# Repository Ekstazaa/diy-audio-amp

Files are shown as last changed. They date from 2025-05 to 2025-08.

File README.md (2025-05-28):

# diy-audio-amp
This is a modular analog audio amplifier project designed for educational and hobby use. It is composed of clearly separated functional blocks such as input stage, voltage amplification, output stage, and power supply – making it easy to understand, modify, or reuse in other designs.

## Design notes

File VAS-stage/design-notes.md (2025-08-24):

# VAS - Voltage Amplifier Stage

The Voltage Amplification Stage (VAS) is a crucial part of any audio power amplifier. Its main role is to amplify the small signal coming from the input stage to a level close to the full supply voltage swing, preparing it to drive the output stage. In other words, the VAS is responsible for faithfully reproducing the input waveform but with a much larger amplitude.

Because of its key role, the operating point of the VAS transistor is extremely important. Poor biasing or incorrect design can lead to severe non-linearity, distortion, and reduced bandwidth.

For beginners, the most common and practical implementation of the VAS is the common-emitter amplifier. This topology provides high voltage gain, good linearity (when properly biased), and simplicity, making it the standard starting point for amplifier design.

## Common Emitter configuration



The circuit shown above is the most classic and academic transistor configuration, making it a great starting point.

Its operation is simple to understand: when the input voltage rises, the NPN transistor begins to conduct heavily, effectively pulling the collector toward ground — the output drops.
When the input voltage decreases, the transistor enters cutoff, and the output approaches the supply voltage.
If we interpret the signals as logic states, this stage acts as an inverter, introducing a 180° phase shift between input and output.

Because of the transistor’s current amplification, a relatively small change in input voltage can produce a large change at the output. This is the foundation of its high voltage gain, making the common-emitter stage a key building block in amplifiers.

### Operating point

### Gain

### Input Impednace

### Output Impedance

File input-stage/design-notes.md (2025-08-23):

## Input stage configurations

For the input stage, the most common solution is a differential pair. The main advantage of this configuration is the ability to apply negative feedback, which can be used to compensate for various non-idealities. For this chapter I will explain basic work of differential pair, parameters and some improvements.

## JFET vs BJT

In audio design books, the best choice for input stages for power amplifiers are.. BJT. The main reasons are their higher linearity, greater gain, and better temperature stability compared to FETs. The only real drawback of BJTs is the presence of base current, which reduces input impedance. However, in most cases, this trade-off is worth it due to the other significant advantages.

# Differential pair



A differential pair is a circuit built from two **identical** transistors with same load supplied by a constant current source. The core idea is that the current through each transistor depends on the voltage difference between the two inputs. If both inputs are equal, the current splits evenly — each side conducts I/2. When vin1 is higher than vin2, more current flows through the transistor on the right side what causes higher voltage on vout2 and vice versa. 



At start let's look at the chart above. It shows how the current through resistors R1 and R2 changes depending on the voltage difference between the inputs (note: negative values indicate that vin1 < vin2).
This graph has few conclusions:

1. The characteristic curve assumes perfectly matched transistors, which means the current splits evenly (I/2) when the voltage difference is exactly 0 V. In reality, transistors can have slight mismatches due to manufacturing tolerances, leading to input offset current or voltage, even when vin1 = vin2.
2. The linear operating region of the differential pair is quite narrow (it is assumed that narrow has 4<sub>*</sub>V<sub>T</sub> = 100 mV for normal configuration). This means the input stage is very sensitive, and even a small voltage difference between the inputs can lead to a significant imbalance in output current - in other words differencial pair has huge gain.
3. As we move further outside the linear range, one of the transistors starts to dominate entirely, conducting nearly the full bias current, while the other one effectively shuts off. At this point, the circuit loses its linear behavior and enters a region where the output no longer changes proportionally to the input difference. In practical terms, this limits show how large the differential input voltage can be **before distortion appears**.

In audio designs the input signal is kept within the linear region otherwise we can introduce distortions to our circuit.

## Gains of differental pair

Just like the differential pair has two inputs, it also has two outputs. Because of that, we can define three different types of voltage gain, depending on how we observe the outputs:
1. Gain measured at `vout1`:

**A<sub>v1</sub> = -R<sub>C</sub> / (2 · r<sub>eb'</sub>) = -1/2 · g<sub>m</sub> · R<sub>C</sub>**

2. Gain measured at `vout2`:

**A<sub>v2</sub> = R<sub>C</sub> / (2 · r<sub>eb'</sub>) = 1/2 · g<sub>m</sub> · R<sub>C</sub>**

3. Differential gain:

**A<sub>v_diff</sub> = R<sub>C</sub> / r<sub>eb'</sub> = g<sub>m</sub> · R<sub>C</sub>**

Where:
- `RC` is the collector resistance,
- `reb' = VT / IC` is the internal emitter resistance,
- `VT` is the thermal voltage (≈ 25 mV at room temperature).

## Input Resistance

As I mentioned earlier when discussing BJTs, one of the key issues is the input impedance, since a continuous base current flows into the transistor.

From the perspective of the PNP transistor currnet is going from emitter to input, so we consider r<sub>b'e</sub> for both transistors in the differential pair:

**R<sub>in</sub> = 2 · r<sub>b'e</sub> = 2 · β · r<sub>eb'</sub>**

## CMRR 

CMRR (Common-Mode Rejection Ratio) is the ability of an amplifier to reject noise that appears equally on both inputs. Formally, it is defined as the ratio between the differential gain (A<sub>diff</sub>) and the common-mode gain(A<sub>cm</sub>) and that mean we would like to have it as huge as it's posible and the best solution is to provide large differential gain.

**CMRR = 20 · log(A<sub>diff</sub>/A<sub>cm</sub>)**

## Load of differential pair

For a differential pair, even with a simple implementation, you can identify three main variants of loading:
a) Unbalanced resistive load
b) Balanced load using resistors
c) Balanced load with a current mirror

In our case, the pair will eventually be loaded by the next stage (VAS), which introduces imbalance between the branches. This makes solution (a), using equal resistors in both collectors, a less attractive choice.

Circuit (b) improves the situation by using a single resistor to balance the load, but this is still only a passive compensation method.
The best solution is (c) — the current mirror load — because the transistor in the unloaded branch biases the other transistor, forcing an identical current in the loaded branch. This ensures excellent balance and better performance. Moreover, method (c) offers the best linearity among the three.



## Slew rate

Slew rate is a parameter that defines how quickly an amplifier can change its output voltage, effectively determining how fast it can turn the next stage on or off.

**Slew rate = dVout/dt = Iss/CL

For a differential pair with a current mirror load, the concept is easier to explain:

- When discharging the load, we assume that transistor M2 is fully on and M1 is off. In that case, the entire tail current from the pair’s current source flows through M2 to ground.

- Conversely, when charging the load, the process also happens with a current equal to the current source value.

Differential pairs with resistive loads typically have an asymmetrical slew rate, because the load resistor diverts part of the current, reducing the effective charging or discharging capability.



# Summary

For final design i used combination below:



If you are using a common differential pair with a current mirror load, there is not much you can adjust beyond selecting the transistors and setting the operating point via the current source. I chose the transistors based on their maximum V<sub>CE</sub> (50 V) for safety, and then balanced cost against noise performance. If you are more precise, you can look at β parameter which is mainly relevant for the input pair, since a higher value ensures greater input impedance.

As the current source, I used a configuration with a transistor biased by diodes and a resistor. I also added a potentiometer to allow fine-tuning if needed, and a capacitor Cf1 for filtering, because some AC signal was leaking into the bias voltage.

Initially, I started with 2.5 mA from the source, but after building the whole configuration I decided to reduce it to 1.88 mA.
Keep in mind that this current not only sets the operating point but also affects your gain — and, more importantly, your slew rate.

As mentioned earlier, slew rate defines how fast your circuit can respond. If it’s too slow, the amplifier can start cutting off higher audio frequencies. If it’s too fast, you risk turning your design into an oscillator due to the effects of negative feedback.

Bibliography:
1. Douglas Self, Audio Power Amplifier Design Handbook 4th edition, Elsevier, 2006
2. R. J. Baker, Circuit Design, Layout, and Simulation 3th Edition, Wiley, 2010

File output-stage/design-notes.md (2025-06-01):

## Output Stage Configurations

Before getting into the test results, I want to briefly go over the most common output stage configurations found in audio amplifiers. The two that come up the most are:

- **CFP – Complementary Feedback Pair (also known as the Sziklai pair)**  
- **EF – Emitter Follower (also known as the Darlington pair)**

Both of these topologies actually come from earlier **quasi-complementary designs**, which were developed when good PNP power transistors weren’t widely available. Nowadays, since complementary NPN/PNP devices are easy to get, using full complementary symmetry just makes more sense.



For this project, I decided to use the **CFP configuration**. After reading Rod Elliott’s article [2], I got the impression that it’s generally better suited for audio amplifiers. It tends to produce less distortion than other topologies. Of course, the actual difference between CFP and EF is often small and usually not audible unless you really know what to listen for — and even then, it can be purely subjective.

Still, from a design perspective, the CFP offers better linearity and thermal behavior, and that was enough for me to go with it.

To wrap up the topic of output stage topologies, I should also mention triple configurations, which basically just add more transistors to the chain. From what I’ve read, these are mostly used in commercial designs, where high current efficiency is a priority. As you can probably guess, that kind of complexity isn’t really necessary for this DIY project.

## Theory of shiklai

Let's look at this configuration:



The Shiklai pair is made of a power transistor (Q1) and control transistor (Q2). The main idea is to make the vout closely follow vin. When vin increases, Q2 starts to conduct more, which means that the base current of Q1 also increases. As a result, the output current delivered to the load goes up, causing vout to rise, so as to ensure a constant voltage drop across Q2's Vbe.

Sziklai pair behaves like a Darlington configuration, but with local negative feedback, which improves linearity and control.

In that configuration i used also ressistor R1. It helps to turn off/on Q1 by creating a voltage drop on Q1's Veb faster. In theory, the resistor should be as small as possible, but a balanced value is needed. If it's too small, it can lead to instability and reduced linearity due to excessive loop gain and insufficient damping.

## Simulations

In the testbench, I used the same current source that will be implemented in the final amplifier design to make the simulation results more realistic. The circuit was tested with a ±10 V, 1 kHz input signal, and the analysis covered 10 cycles. A 32 Ω resistor was used as the load:

Screenshot of testbench:



The two main things I can tweak are the transistors in the Sziklai pair and the resistors. For the control transistors, I chose BC556B and BC557B, mainly to keep the design coherent — differencial pair, current soures and VAS I used the same.

As for the power transistors, I went with 2SA1943 and 2SC5200. I picked these mostly based on cost and availability. Honestly, I don’t have much experience with selecting "ideal" transistors yet, so I just chose the most common and affordable ones I could find.

After analyzing the transistors, I tested the influence of resistors R1 and R2 by sweeping their values in LTspice.

| R [Ω] | THD [%] | AVG(i(vup)) [mA] | AVG(i(vdn)) [mA] |
|---|---|---|---|
| 100 | 0.0885  | 108.936 | -88.531 |
| 200 | 0.0689  | 109.449 | -89.033 |
| 300 | 0.0808  | 111.864 | -91.442 |
| 400 | 0.0808  | 113.779 | -93.353 |
| 500 | 0.0775  | 115.219 | -94.790 |
| 600 | 0.0753  | 116.255 | -95.824 |
| 700 | 0.0724  | 117.143 | -96.712 |
| 800 | 0.0704  | 117.841 | -97.408 |
| 900 | 0.0676  | 118.486 | -98.054 |
| 1000  | 0.0659  | 119.007 | -98.575 |
| 2000  | 0.0554  | 122.078 | -101.644 |
| 3000  | 0.0513  | 123.594 | -103.158 |
| 4000  | 0.0492  | 124.566 | -104.128 |
| 5000  | 0.0476  | 125.261 | -104.827 |
| 10000 | 0.0439  | 127.274 | -106.830 |

As a reminder, the resistor is used to accelerate the switching of the power transistors. The chart shows that when the resistance is high, the circuit struggles to turn off transistors Q1 and Q3. For values around 10 kΩ and higher, the transistors remain on throughout the entire cycle and operate in saturation. This indicates that the circuit behaves like a Class A amplifier.

Additionally, the average current through the branch increases with higher resistance values. To reduce power consumption, lower resistor values are needed. However, this comes with a trade-off: reducing the resistance increases THD and decreases linearity (you can see the breakdown in the characteristic). As always, it’s a matter of compromise.

I initially spent a lot of time analyzing that configuration for myself, but in practice, using 100Ω, 200Ω, or 300Ω doesn't really make much of a difference, since the resistance will drift with temperature regardless. The safest option is to choose a 330 Ω resistor from the E6 series.



Bibliography:
1. Douglas Self, Audio Power Amplifier Design Handbook 4th edition, Elsevier, 2006
2. Rod Elliott, Compound Pair Vs. Darlington Pairs, https://sound-au.com/articles/cmpd-vs-darl.htm, 2011

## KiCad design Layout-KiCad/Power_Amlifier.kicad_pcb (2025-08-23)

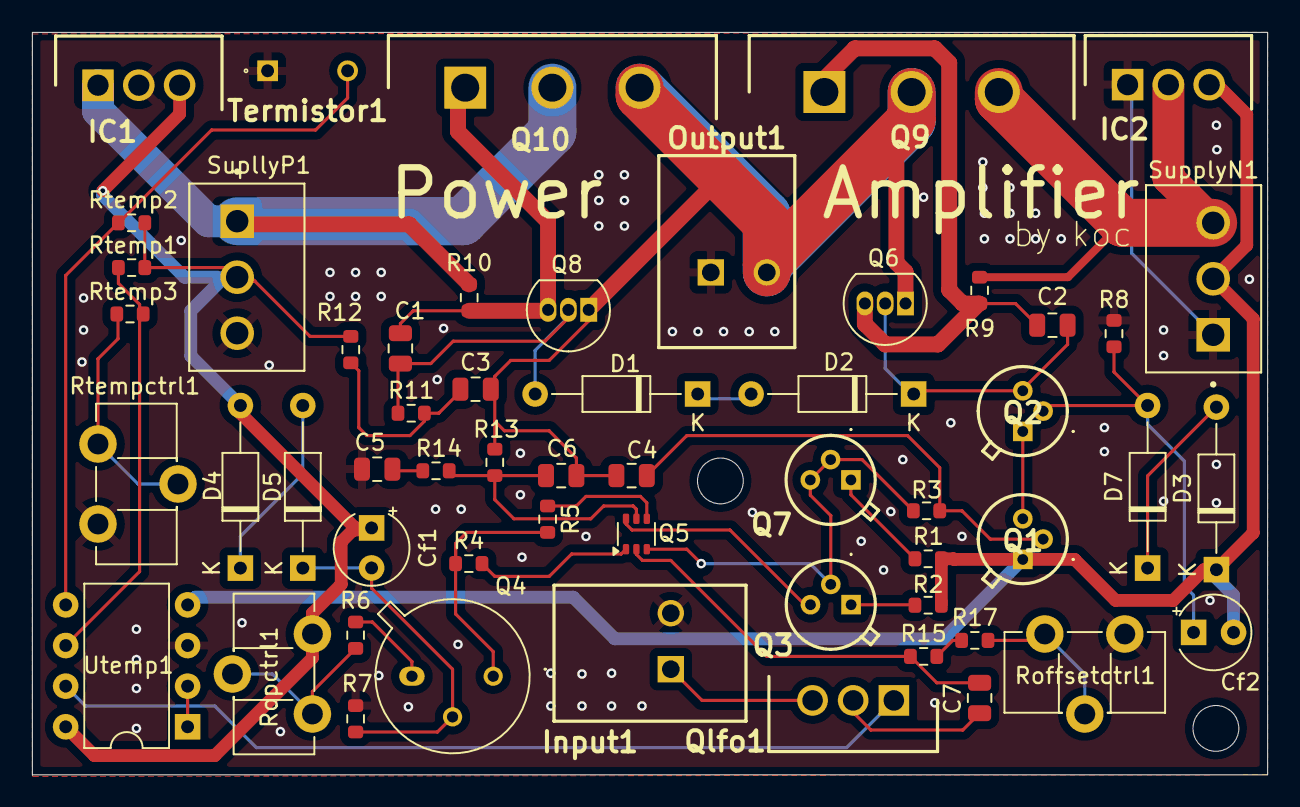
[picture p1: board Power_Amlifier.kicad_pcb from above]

Board: 2 copper layers, 77.2 x 46.4 mm, 56 parts (0 on the bottom side), 39 nets.

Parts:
C1, C2: 100p; C_0805_2012Metric
C3, C5: 10u; C_0805_2012Metric
C4: 470p; C_0805_2012Metric
C6: 2p2; C_0805_2012Metric
C7: 1.5n; C_0805_2012Metric
Cf1, Cf2: 100u; CP_Radial_Tantal_D4.5mm_P2.50mm
D1, D2, D3, D4, D5, D7: 1N914; D_DO-35_SOD27_P10.16mm_Horizontal
IC1, IC2: L7824CV; TO255P460X1020X2008-3P
Input1: 250-102; 250102
Output1: 250-102; 250102
Q1, Q2, Q3, Q7: 2N2484
Q4: BC303; TO-39-3
Q5: BC856BS; SOT-363_SC-70-6
Q6: Q_PNP_EBC; TO-92_Inline
Q8: Q_NPN_EBC; TO-92_Inline
Q9: 2SC5200-O_Q_; TO545P520X2000X2900-3P
Q10: 2SA1943-O_Q_; TO545P520X2050X2650-3P
Qlfo1: IRFZ34NPBF; TO254P469X1042X1967-3P
R1, R2: 220; R_0603_1608Metric
R3: 1; R_0603_1608Metric
R4, R5: 100; R_0603_1608Metric
R6, R9, R10: 330; R_0603_1608Metric
R7, R11, R12, R17: 10k; R_0603_1608Metric
R8: 470k; R_0603_1608Metric
R13: 220k; R_0603_1608Metric
R14: 11k; R_0603_1608Metric
R15: 200k; R_0603_1608Metric
Roffsetctrl1: R20k; Potentiometer_ACP_CA9-H5_Horizontal
Ropctrl1: R1k; Potentiometer_ACP_CA9-H5_Horizontal
Rtemp1, Rtemp2: 47k; R_0603_1608Metric
Rtemp3: 5k; R_0603_1608Metric
Rtempctrl1: R10k; Potentiometer_ACP_CA9-H5_Horizontal
SupllyP1: TBP03R2-350-03BE; CUI_TBP03R2-350-03BE
SupplyN1: TBP03R2-350-03BE; CUI_TBP03R2-350-03BE
Termistor1: B57164K0103K000; B57164K_K164
Utemp1: Opamp_Dual; DIP-8_W7.62mm

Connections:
+24V: Cf1.1, D4.2 (A), IC1.3 (OUTPUT), R12.2, Ropctrl1.3, Rtemp1.2, Rtemp2.2, SupllyP1.2, Utemp1.8 (V+)
+30V: IC1.1 (INPUT), Q10.2 (COLLECTOR_(HEAT_SINK)), R10.2, SupllyP1.1
-24V: Cf2.2, D3.1 (K), IC2.3 (OUTPUT), Q1.1 (E), R1.1, R2.1, SupplyN1.2, Utemp1.4 (V-)
-30V: IC2.2 (GROUND), Q9.3 (E), R9.1, SupplyN1.3
GND: C5.1, IC1.2 (GROUND), IC2.1 (INPUT), Input1.2, Output1.1, R7.1, R8.2, Roffsetctrl1.1, Rtempctrl1.3, SupllyP1.3, SupplyN1.1, Termistor1.1, Utemp1.3 (+)
unnamed: C3.1, R11.2, R12.1
unnamed: C5.2, R14.2
unnamed: C1.1, D1.2 (A), Q8.2 (B), R11.1
unnamed: D1.1 (K), D2.2 (A)
unnamed: C2.1, D2.1 (K), Q2.3 (C), Q6.2 (B)
unnamed: D3.2 (A), D7.1 (K)
unnamed: D4.1 (K), D5.2 (A)
unnamed: Cf1.2, D5.1 (K), Q4.2 (B), R7.2
unnamed: Cf2.1, D7.2 (A), Q2.2 (B), R8.1
unnamed: C4.1, Q1.2 (B), R3.1
unnamed: Q1.3 (C), Q2.1 (E)
unnamed: Q3.2 (B), Q5.3 (C2), Q7.2 (B), Q7.3 (C), R3.2
unnamed: Q3.3 (C), Q5.6 (C1)
unnamed: Q3.1 (E), R2.2
unnamed: Q4.3 (C), R4.1, R5.2
unnamed: Q4.1 (E), R6.1
unnamed: C7.2, Q5.2 (B1), R15.1
unnamed: Q5.1 (E1), R4.2
unnamed: C6.1, Q5.5 (B2), R13.2, R14.1
unnamed: Q5.4 (E2), R5.1
unnamed: C2.2, Q6.3 (C), Q9.1 (B), R9.2
unnamed: Q7.1 (E), R1.2
unnamed: C1.2, Q8.3 (C), Q10.1 (BASE), R10.1
unnamed: C3.2, C4.2, C6.2, Output1.2, Q6.1 (E), Q8.1 (E), Q9.2 (C), Q10.3 (EMITTER), R13.1
unnamed: C7.1, Qlfo1.2 (D)
unnamed: Input1.1, Qlfo1.3 (S)
unnamed: R6.2, Ropctrl1.1, Ropctrl1.2
unnamed: R15.2, R17.1
unnamed: R17.2, Roffsetctrl1.2, Roffsetctrl1.3
unnamed: Rtemp3.2, Rtempctrl1.1, Rtempctrl1.2
unnamed: Utemp1.1, Utemp1.2 (-)
unnamed: Rtemp2.1, Termistor1.2, Utemp1.5 (+)
unnamed: Rtemp1.1, Rtemp3.1, Utemp1.6 (-)
Vcntrl: Qlfo1.1 (G), Utemp1.7

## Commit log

2025-05-29 Update design-notes.md
    added theory of output stage
2025-05-31 Update design-notes.md
    description of added resistors and transistors
2025-06-01 Update design-notes.md
    resumalte with realistic current source
2025-06-01 Create output_stage_tran_tb
    tb for output stage
2025-06-02 testbench of input stage + vas
2025-07-08 Layout of amplifier
    [Power_Amlifier.kicad_pcb, Power_Amlifier.kicad_sch]
2025-08-23 added files of amplifer's pcb
    [Power_Amlifier.kicad_pcb, Power_Amlifier.kicad_sch]
